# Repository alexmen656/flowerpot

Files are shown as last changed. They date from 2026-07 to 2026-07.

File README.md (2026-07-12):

# Smart Flower Pot

With this smart flower pot you will never forget to water your plants. If you don't water it within a time interval you can set on the screen, 3 speakers will scream at you until the motion sensor detects movement (you watering the plant) - it won't stop. It also monitors the humidity, temperature and light conditions of your plant and displays it on the screen.

## BOM

| Qty | Part | Source |
|-----|---|---|
| 3 | Speakers | [AliExpress](https://de.aliexpress.com/item/1005010806449882.html) |
| 3 | Amplifiers | [AliExpress](https://de.aliexpress.com/item/1005012452360614.html) |
| 1 | Orpheus Pico | Got it from HackClub |
| 1 | XIAO RP2040 | [AliExpress](https://de.aliexpress.com/item/1005012441490478.html) |
| - | Jumper wires | Like a lot of them! |
| 1 | 2.8" TFT display | [AliExpress](https://de.aliexpress.com/item/1005010008924503.html) |
| - | 3D printer filament (for the pot) | Any filament |
| 1 | DHT11 sensor | [AliExpress](https://de.aliexpress.com/item/1005008953430940.html) |
| 1 | Motion sensor (HC-SR501) | [AliExpress](https://de.aliexpress.com/item/4001234886268.html) |

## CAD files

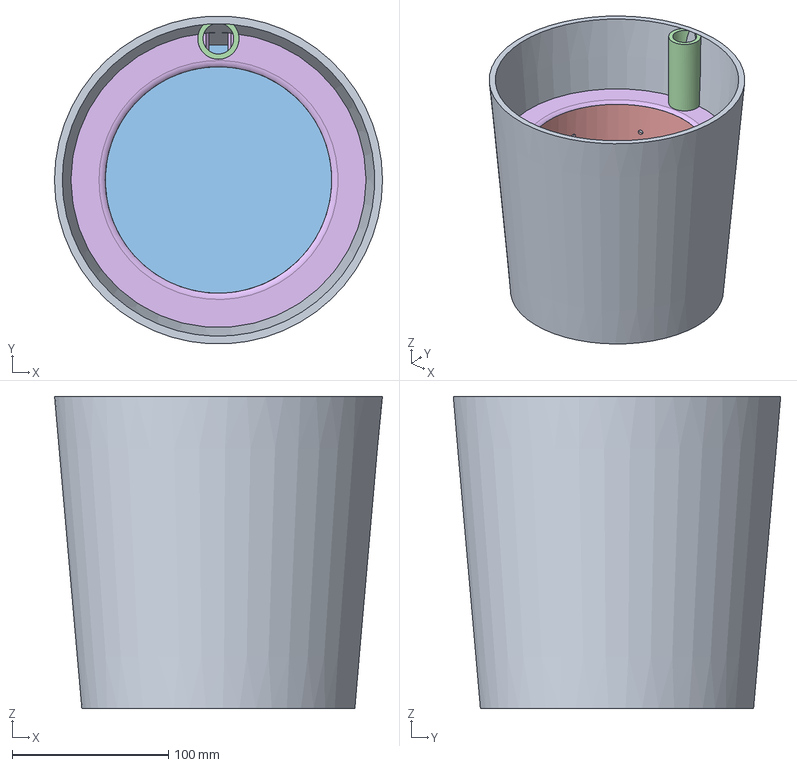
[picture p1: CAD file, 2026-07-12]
CAD/plant_pot.stp
210.0 x 209.6 x 200.0 mm

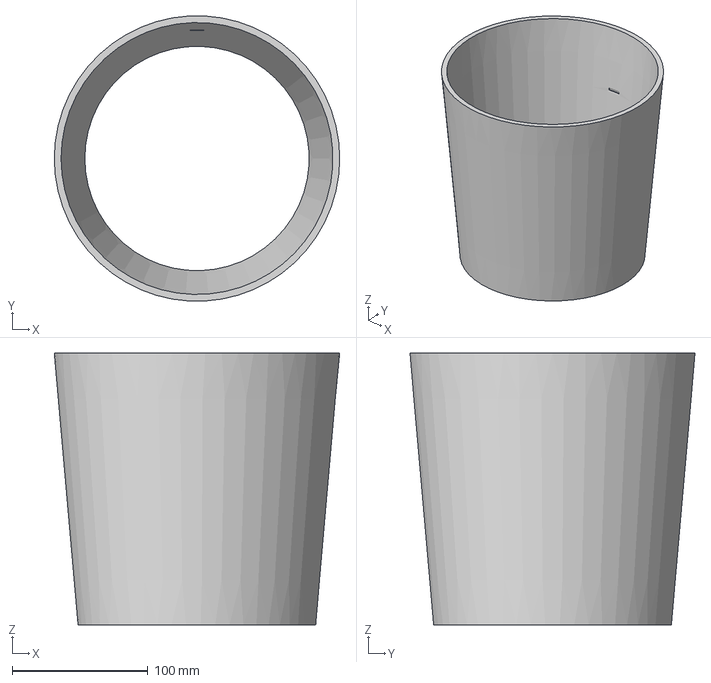
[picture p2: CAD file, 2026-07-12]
CAD/plant_pot_top.step
210.0 x 209.6 x 200.0 mm

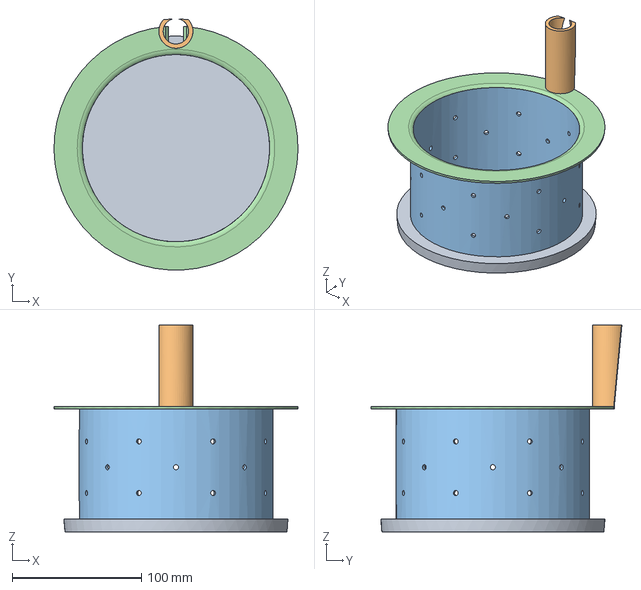
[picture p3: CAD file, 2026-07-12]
CAD/plant_pot_middle.step
189.0 x 194.3 x 160.0 mm

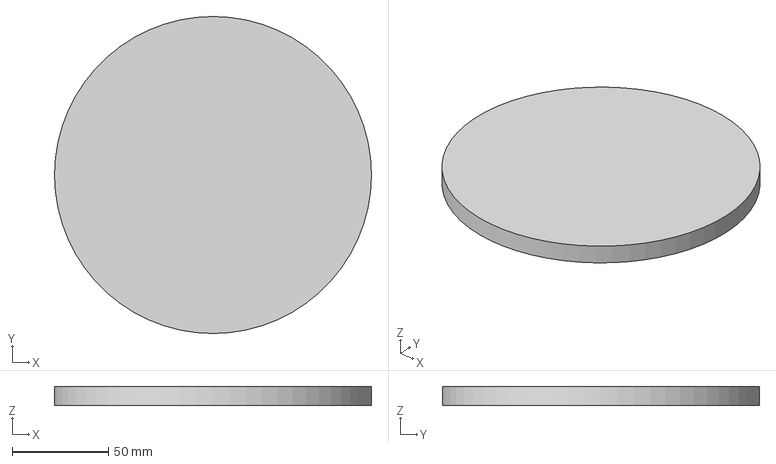
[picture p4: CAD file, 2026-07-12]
CAD/plant_pot_bottom.step
165.0 x 165.0 x 10.0 mm

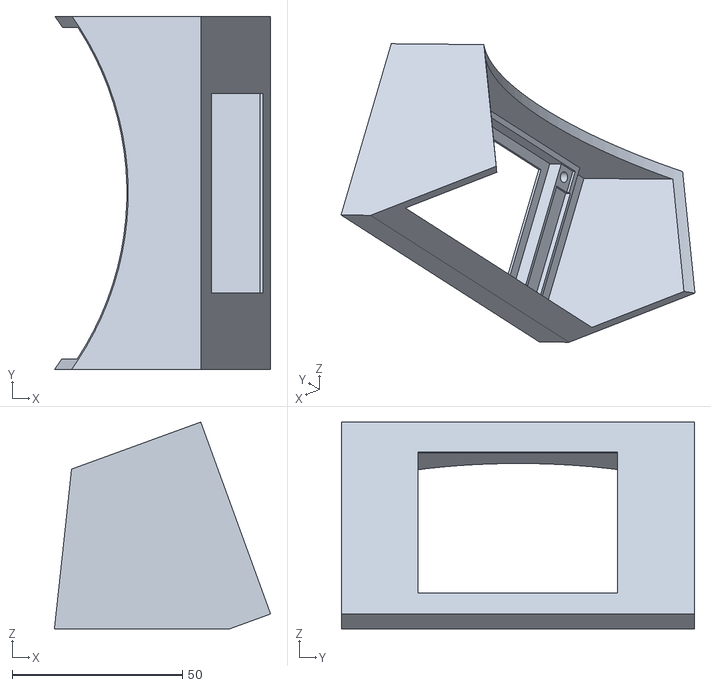
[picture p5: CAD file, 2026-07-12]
CAD/display.stl
63.6 x 103.7 x 60.8

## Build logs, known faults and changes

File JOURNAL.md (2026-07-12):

# 1. CAD - around 2 hours
The CAD was pretty simple and straightforward

# 2. Putting everything together - 8 hours
This was the hardest part because of the many components I had to solder together. The speakers were very frustrating because they needed amplifiers, so I had to solder around 15 wires for each speaker. The rest wasn't that hard, just time consuming

# 3. Adding a Display - 3 hours
Initially I didn't plan to have a display, but then I decided later that it would be much cooler to have one - so I designed the display cover and added a 2.8 inch TFT screen

# 4. Idea for adding a LED strip
I also wanted to add a LED strip to the top, but the Pico didn't have enough power, so I didn't finish that.

# 5. Firmware - 2 hours
Firmware was a bit more complicated than I thought. TBH, AI assisted me with this step for like 50%, because the display added much more complexity with displaying a nice layout and icons. I used MicroPython for the firmware

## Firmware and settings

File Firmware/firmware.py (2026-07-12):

import machine
import random
import time
from micropython import const
import ustruct as struct
import math
import dht  # DHT11/DHT22 sensor support
from machine import I2S, Pin
import array

# ILI9341 command set
ILI9341_SWRESET = const(0x01)
ILI9341_SLPOUT = const(0x11)
ILI9341_DISPON = const(0x29)
ILI9341_CASET = const(0x2A)
ILI9341_PASET = const(0x2B)
ILI9341_RAMWR = const(0x2C)
ILI9341_MADCTL = const(0x36)
ILI9341_PIXFMT = const(0x3A)
ILI9341_PWCTR1 = const(0xC0)
ILI9341_PWCTR2 = const(0xC1)
ILI9341_VMCTR1 = const(0xC5)
ILI9341_VMCTR2 = const(0xC7)
ILI9341_FRMCTR1 = const(0xB1)
ILI9341_DFUNCTR = const(0xB6)
ILI9341_GAMMASET = const(0x26)
ILI9341_GMCTRP1 = const(0xE0)
ILI9341_GMCTRN1 = const(0xE1)

MADCTL_MX = const(0x40)
MADCTL_BGR = const(0x08)

# Color palette (RGB565)
GREEN_LIGHT = const(0x87E0)
GREEN_DARK = const(0x0400)
BLUE_LIGHT = const(0x3D7F)
BLUE_DARK = const(0x001F)
ORANGE = const(0xFD20)
RED = const(0xF800)
YELLOW = const(0xFFE0)
WHITE = const(0xFFFF)
BLACK = const(0x0000)
GRAY_LIGHT = const(0xCE79)
GRAY_DARK = const(0x7BEF)
BROWN = const(0x8200)

# Touch controller commands (XPT2046/ADS7843)
TOUCH_CMD_X = const(0x90)
TOUCH_CMD_Y = const(0xD0)

def delay_ms(ms):
    time.sleep_ms(ms)

def color565(r, g=0, b=0):
    """Convert RGB to 565 format"""
    try:
        r, g, b = r
    except TypeError:
        pass
    return (r & 0xf8) << 8 | (g & 0xfc) << 3 | b >> 3

class TouchController:
    def __init__(self, spi, cs, irq):
        self.spi = spi
        self.cs = cs
        self.irq = irq
        self.cs.on()  # CS high (inactive)

        # Calibration values, may need adjusting per panel
        self.cal_x_min = 200
        self.cal_x_max = 3800
        self.cal_y_min = 200
        self.cal_y_max = 3800

        self.test_connection()

    def test_connection(self):
        """Tests the connection to the touch controller"""
        print("Testing touch controller connection...")

        irq_state = self.irq.value()
        print(f"IRQ pin state: {irq_state} (1=no touch, 0=touch detected)")

        try:
            test_x = self.read_touch_raw(TOUCH_CMD_X)
            test_y = self.read_touch_raw(TOUCH_CMD_Y)
            print(f"Touch test values: X={test_x}, Y={test_y}")

            if test_x == 0 and test_y == 0:
                print("Warning: touch controller not responding correctly")
            else:
                print("Touch controller responding")

        except Exception as e:
            print(f"Touch controller error: {e}")

    def read_touch_raw(self, cmd):
        """Reads a raw touch sample"""
        self.cs.off()
        delay_ms(1)

        self.spi.write(bytes([cmd]))

        delay_ms(1)
        result = self.spi.read(2)

        delay_ms(1)
        self.cs.on()

        if len(result) == 2:
            # 12-bit resolution (ADS7843/XPT2046)
            value = (result[0] << 8 | result[1]) >> 3
            return value & 0x0FFF
        return 0

    def get_touch(self):
        """Returns the touch position, or None if there's no touch"""
        irq_state = self.irq.value()

        if irq_state == 1:  # IRQ is HIGH when not pressed
            return None

        # Average a few samples for stability
        x_sum = y_sum = 0
        valid_readings = 0

        for i in range(3):
            x_raw = self.read_touch_raw(TOUCH_CMD_X)
            y_raw = self.read_touch_raw(TOUCH_CMD_Y)

            if i == 0:
                print(f"Touch raw: X={x_raw}, Y={y_raw}, IRQ={irq_state}")

            if x_raw > 100 and y_raw > 100 and x_raw < 4000 and y_raw < 4000:
                x_sum += x_raw
                y_sum += y_raw
                valid_readings += 1

        if valid_readings == 0:
            print("No valid touch readings")
            return None

        x_avg = x_sum // valid_readings
        y_avg = y_sum // valid_readings

        # Map to screen coordinates
        x = int((x_avg - self.cal_x_min) * 320 / (self.cal_x_max - self.cal_x_min))
        y = int((y_avg - self.cal_y_min) * 240 / (self.cal_y_max - self.cal_y_min))

        x = max(0, min(319, x))
        y = max(0, min(239, y))

        print(f"Touch calculated: X={x}, Y={y} (raw avg: {x_avg}, {y_avg})")
        return (x, y)

class SmartPlantDisplay:
    def __init__(self, spi, dc, reset, cs=None, touch=None):
        self.spi = spi
        self.dc = dc
        self.reset = reset
        self.cs = cs
        self.touch = touch
        self.width = 320
        self.height = 240
        self.current_screen = 0
        self.last_update = 0
        self.last_touch_time = 0
        self.manual_mode = False  # touch disables auto screen switching
        self.last_drawn_screen = -1
        self.screen_needs_redraw = True
        self.last_light_value = 0
        self.data_needs_update = False  # value-only update without full redraw

        # Motion sensor tracking
        self.last_motion_time = 0
        self.motion_timeout = 30000  # ms, adjustable
        self.motion_timeout_seconds = 30  # for UI display, adjustable
        self.last_motion_check = 0
        self.audio_played = False
        self.reward_played = False

        # I2S audio system for punishment/reward sounds
        self.i2s = None
        self.setup_audio_system()

        # Last displayed values, for change detection
        self.last_displayed_values = {
            'light': 0,
            'temperature': 0,
            'humidity': 0,
            'plant_health': 0
        }

        # Sensors
        self.light_sensor = machine.ADC(machine.Pin(28))  # GP28 = ADC2, light sensor
        self.dht_sensor = dht.DHT11(machine.Pin(27))      # GP27, temp/humidity sensor
        self.motion_pin = machine.Pin(26, machine.Pin.IN) # GP26, motion sensor

        current_time = time.ticks_ms()
        self.last_motion_time = current_time  # start as if motion was just detected
        print(f"Motion sensor initialized - {self.motion_timeout_seconds}s timer started")

        # Simulated sensor data, used as fallback when a real sensor is unavailable
        self.sensor_data = {
            'temperature': 22.5,
            'humidity': 65,
            'light': 750,
            'light_voltage': 1.65,
            'light_raw': 32767,
            'water_level': 80,
            'plant_health': 85
        }

    # Low-level display functions
    def dc_low(self):
        self.dc.off()

    def dc_high(self):
        self.dc.on()

    def cs_low(self):
        if self.cs:
            self.cs.off()

    def cs_high(self):
        if self.cs:
            self.cs.on()

    def write_cmd(self, cmd):
        self.cs_low()
        self.dc_low()
        self.spi.write(bytes([cmd]))
        self.cs_high()

    def write_data(self, data):
        self.cs_low()
        self.dc_high()
        if isinstance(data, int):
            self.spi.write(bytes([data]))
        else:
            self.spi.write(data)
        self.cs_high()

    def write_cmd_data(self, cmd, data=None):
        self.cs_low()
        self.dc_low()
        self.spi.write(bytes([cmd]))
        if data is not None:
            self.dc_high()
            if isinstance(data, int):
                self.spi.write(bytes([data]))
            else:
                self.spi.write(data)
        self.cs_high()

    def init(self):
        """Initializes the display controller"""
        print("Initializing display...")

        if self.reset:
            self.reset.off()
            delay_ms(100)
            self.reset.on()
            delay_ms(100)

        self.write_cmd(ILI9341_SWRESET)
        delay_ms(150)

        self.write_cmd(ILI9341_SLPOUT)
        delay_ms(120)

        self.write_cmd_data(0xCB, bytes([0x39, 0x2C, 0x00, 0x34, 0x02]))
        self.write_cmd_data(0xCF, bytes([0x00, 0xC1, 0x30]))
        self.write_cmd_data(ILI9341_PWCTR1, 0x23)
        self.write_cmd_data(ILI9341_PWCTR2, 0x10)
        self.write_cmd_data(ILI9341_VMCTR1, bytes([0x3e, 0x28]))
        self.write_cmd_data(ILI9341_VMCTR2, 0x86)
        self.write_cmd_data(ILI9341_MADCTL, 0x88)  # MY(0x80) | BGR(0x08), 270° rotation
        self.write_cmd_data(ILI9341_PIXFMT, 0x55)
        self.write_cmd_data(ILI9341_FRMCTR1, bytes([0x00, 0x18]))

        self.write_cmd(ILI9341_DISPON)
        delay_ms(100)

        print("Display ready")

    def set_window(self, x0, y0, x1, y1):
        self.write_cmd_data(ILI9341_CASET, struct.pack(">HH", x0, x1))
        self.write_cmd_data(ILI9341_PASET, struct.pack(">HH", y0, y1))
        self.write_cmd(ILI9341_RAMWR)

    def fill_rect(self, x, y, w, h, color):
        if x + w > self.width:
            w = self.width - x
        if y + h > self.height:
            h = self.height - y

        self.set_window(x, y, x + w - 1, y + h - 1)
        pixel_data = struct.pack(">H", color)

        self.cs_low()
        self.dc_high()
        for _ in range(w * h):
            self.spi.write(pixel_data)
        self.cs_high()

    def fill(self, color):
        self.fill_rect(0, 0, self.width, self.height, color)

    def pixel(self, x, y, color):
        if 0 <= x < self.width and 0 <= y < self.height:
            self.set_window(x, y, x, y)
            self.write_data(struct.pack(">H", color))

    def hline(self, x, y, w, color):
        self.fill_rect(x, y, w, 1, color)

    def vline(self, x, y, h, color):
        self.fill_rect(x, y, 1, h, color)

    # UI drawing helpers
    def draw_rounded_rect(self, x, y, w, h, radius, color):
        """Draws a rounded rectangle"""
        self.fill_rect(x + radius, y, w - 2*radius, h, color)
        self.fill_rect(x, y + radius, radius, h - 2*radius, color)
        self.fill_rect(x + w - radius, y + radius, radius, h - 2*radius, color)

        # Corners
        for i in range(radius):
            for j in range(radius):
                if i*i + j*j <= radius*radius:
                    self.pixel(x + radius - i, y + radius - j, color)
                    self.pixel(x + w - radius + i, y + radius - j, color)
                    self.pixel(x + radius - i, y + h - radius + j, color)
                    self.pixel(x + w - radius + i, y + h - radius + j, color)

    def draw_circle(self, cx, cy, radius, color):
        """Draws a filled circle"""
        for x in range(-radius, radius + 1):
            for y in range(-radius, radius + 1):
                if x*x + y*y <= radius*radius:
                    self.pixel(cx + x, cy + y, color)

    def draw_progress_bar(self, x, y, w, h, value, max_value, bg_color, fg_color):
        """Draws a progress bar"""
        self.draw_rounded_rect(x, y, w, h, 3, bg_color)

        progress_w = int((value / max_value) * (w - 4))
        if progress_w > 0:
            self.draw_rounded_rect(x + 2, y + 2, progress_w, h - 4, 2, fg_color)

    def draw_digit(self, x, y, digit, size, color):
        """Draws a single digit as a 7-segment display"""
        segments = [
            [1,1,1,1,1,1,0], # 0
            [0,1,1,0,0,0,0], # 1
            [1,1,0,1,1,0,1], # 2
            [1,1,1,1,0,0,1], # 3
            [0,1,1,0,0,1,1], # 4
            [1,0,1,1,0,1,1], # 5
            [1,0,1,1,1,1,1], # 6
            [1,1,1,0,0,0,0], # 7
            [1,1,1,1,1,1,1], # 8
            [1,1,1,1,0,1,1]  # 9
        ]

        if 0 <= digit <= 9:
            seg = segments[digit]
            w = size * 6
            h = size * 10

            if seg[0]: self.fill_rect(x+size, y, w-2*size, size, color)           # top
            if seg[1]: self.fill_rect(x+w-size, y+size, size, h//2-size, color)  # top right
            if seg[2]: self.fill_rect(x+w-size, y+h//2, size, h//2-size, color)  # bottom right
            if seg[3]: self.fill_rect(x+size, y+h-size, w-2*size, size, color)   # bottom
            if seg[4]: self.fill_rect(x, y+h//2, size, h//2-size, color)         # bottom left
            if seg[5]: self.fill_rect(x, y+size, size, h//2-size, color)         # top left
            if seg[6]: self.fill_rect(x+size, y+h//2-size//2, w-2*size, size, color) # middle

    def draw_number(self, x, y, number, size, color):
        """Draws a multi-digit number"""
        num_str = str(int(number))
        digit_width = size * 8

        for i, digit_char in enumerate(num_str):
            digit = int(digit_char)
            digit_x = x + i * digit_width
            self.draw_digit(digit_x, y, digit, size, color)

    def draw_icon_plant(self, x, y, size, color):
        """Draws a plant icon"""
        stem_x = x + size // 2
        self.vline(stem_x, y + size//3, size//2, GREEN_DARK)

        self.draw_circle(x + size//4, y + size//4, size//6, color)
        self.draw_circle(x + 3*size//4, y + size//4, size//6, color)
        self.draw_circle(x + size//2, y + size//6, size//5, color)

    def draw_icon_water(self, x, y, size, color):
        """Draws a water drop icon"""
        self.draw_circle(x + size//2, y + size//2, size//3, color)

    def draw_icon_temperature(self, x, y, size, color):
        """Draws a thermometer icon"""
        therm_x = x + size//2
        self.vline(therm_x, y + size//4, size//2, color)
        self.draw_circle(therm_x, y + 3*size//4, size//8, color)

    def draw_icon_sun(self, x, y, size, color):
        """Draws a sun icon"""
        center_x, center_y = x + size//2, y + size//2
        radius = size//4

        for angle in range(0, 360, 45):
            angle_rad = angle * 3.14159 / 180
            x1 = center_x + int(radius * 1.5 * math.cos(angle_rad))
            y1 = center_y + int(radius * 1.5 * math.sin(angle_rad))
            x2 = center_x + int(radius * 2 * math.cos(angle_rad))
            y2 = center_y + int(radius * 2 * math.sin(angle_rad))

            for i in range(3):
                if 0 <= x1+i < self.width and 0 <= y1 < self.height:
                    self.pixel(x1+i, y1, color)

        self.draw_circle(center_x, center_y, radius, color)

    def read_light_sensor(self):
        """Reads the light sensor (ADC)"""
        try:
            raw = self.light_sensor.read_u16()  # 0 to 65535
            voltage = raw * 3.3 / 65535

            # Map to a lux-like range (0-1000); may need calibration
            light_value = int((raw / 65535) * 1000)

            return light_value, voltage, raw
        except Exception as e:
            print(f"Light sensor error: {e}")
            return 500, 1.65, 32767  # fallback values

    def read_temp_humidity_sensor(self):
        """Reads the DHT11 temperature/humidity sensor"""
        try:
            self.dht_sensor.measure()
            temperature = self.dht_sensor.temperature()
            humidity = self.dht_sensor.humidity()

            print(f"DHT11 - Temp: {temperature}C, Humidity: {humidity}%")
            return temperature, humidity

        except OSError as e:
            print(f"DHT11 sensor error: {e} (not connected or faulty?)")
            return None, None
        except Exception as e:
            print(f"DHT11 unknown error: {e}")
            return None, None

    def read_motion_sensor(self):
        """Reads the motion sensor and triggers reward/punishment audio based on the timeout"""
        try:
            current_time = time.ticks_ms()
            motion_state = self.motion_pin.value()

            if motion_state == 1:  # motion detected -> reward
                self.last_motion_time = current_time
                self.audio_played = False

                # Only play the reward sound once per motion event
                if not self.reward_played:
                    print("Motion detected - watering detected")
                    self.play_reward_sound()
                    self.reward_played = True

                return True
            else:
                self.reward_played = False

            # Check the timeout every 5s to avoid spamming
            if time.ticks_diff(current_time, self.last_motion_check) > 5000:
                self.last_motion_check = current_time

                if time.ticks_diff(current_time, self.last_motion_time) > self.motion_timeout:
                    print(f"No motion for {self.motion_timeout_seconds}+ seconds - punishment")

                    # Only play the punishment sound once per timeout period
                    if not self.audio_played:
                        self.play_punishment_sound()
                        self.audio_played = True

            return False

        except Exception as e:
            print(f"Motion sensor error: {e}")
            return False

    def setup_audio_system(self):
        """Initializes the I2S audio system"""
        try:
            self.i2s = I2S(
                0,
                sck=Pin(10),    # BCLK
                ws=Pin(11),     # LRC / WS
                sd=Pin(12),     # DIN
                mode=I2S.TX,
                bits=16,
                format=I2S.MONO,
                rate=22050,
                ibuf=20000,
            )
            print("I2S audio system initialized (GP10=BCLK, GP11=WS, GP12=DIN)")
        except Exception as e:
            print(f"I2S audio system error: {e}")
            self.i2s = None

    def play_punishment_sound(self):
        """Plays the punishment sound: a 5s, 3000 Hz sine wave"""
        if not self.i2s:
            print("I2S not available - no sound")
            return

        try:
            print("Punishment: playing sine wave (5s, 3000 Hz)")

            sample_rate = 22050
            frequency = 3000
            amplitude = 32767  # max for 16-bit audio
            duration = 5
            samples_per_cycle = sample_rate // frequency

            sine_wave = array.array("h", [
                int(amplitude * math.sin(2 * math.pi * i / samples_per_cycle))
                for i in range(samples_per_cycle)
            ])

            num_cycles = int(sample_rate * duration // samples_per_cycle)
            for cycle in range(num_cycles):
                self.i2s.write(sine_wave)
                if cycle % 50 == 0:
                    time.sleep_ms(1)

            print("Punishment sound finished")

        except Exception as e:
            print(f"Audio playback error: {e}")

    def play_reward_sound(self):
        """Plays the reward sound: a short major-chord melody"""
        if not self.i2s:
            print("I2S not available - no reward sound")
            return

        try:
            print("Reward: playing melody (good plant care!)")

            sample_rate = 22050
            amplitude = 16383  # quieter than the punishment sound
            duration = 2

            # C major triad progression
            frequencies = [
                261.63,  # C4
                329.63,  # E4
                392.00,  # G4
                523.25   # C5
            ]

            note_duration = 0.5

            for freq in frequencies:
                samples_per_cycle = sample_rate // int(freq)

                sine_wave = array.array("h", [
                    int(amplitude * math.sin(2 * math.pi * i / samples_per_cycle))
                    for i in range(samples_per_cycle)
                ])

                num_cycles = int(sample_rate * note_duration // samples_per_cycle)
                for cycle in range(num_cycles):
                    self.i2s.write(sine_wave)
                    if cycle % 20 == 0:
                        time.sleep_ms(1)

            print("Reward melody finished")

        except Exception as e:
            print(f"Reward audio error: {e}")

    def cleanup_audio(self):
        """Tears down the audio system"""
        if self.i2s:
            try:
                self.i2s.deinit()
                print("I2S audio system stopped")
            except:
                pass
            self.i2s = None

    def show_main_screen(self):
        """Draws the main dashboard screen"""
        self.fill(BLACK)

        y_start = 20

        # Row 1: temperature (1 box) + light (2 boxes)
        color = GRAY_LIGHT

        # Temperature widget
        self.draw_rounded_rect(10, y_start, 90, 80, 8, color)
        self.draw_icon_temperature(20, y_start + 10, 30, ORANGE)
        self.draw_number(20, y_start + 45, self.sensor_data['temperature'], 2, ORANGE)

        # Light widget, spans 2 boxes
        light_value = int(self.sensor_data['light'])
        light_color = self.get_light_quality_color(light_value)
        light_description = self.get_light_quality_description(light_value)

        self.draw_rounded_rect(110, y_start, 200, 80, 8, color)
        self.draw_icon_sun(120, y_start + 10, 60, light_color)

        # Light quality label, next to the icon
        text_x = 190
        text_y = y_start + 20

        if len(light_description) > 10:
            words = light_description.split()
            if len(words) >= 2:
                self.draw_simple_text_2x(text_x, text_y, words[0], light_color)
                self.draw_simple_text_2x(text_x, text_y + 20, words[1], light_color)
            else:
                short_desc = light_description[:10]
                self.draw_simple_text_2x(text_x, text_y, short_desc, light_color)
        else:
            self.draw_simple_text_2x(text_x, text_y, light_description, light_color)

        # Row 2: humidity (1 box) + plant health (2 boxes)
        self.draw_rounded_rect(10, y_start + 90, 90, 80, 8, color)
        self.draw_icon_water(20, y_start + 100, 30, BLUE_LIGHT)
        self.draw_number(20, y_start + 135, self.sensor_data['humidity'], 2, BLUE_LIGHT)

        self.draw_rounded_rect(110, y_start + 90, 200, 80, 8, color)
        health = self.sensor_data['plant_health']

        if health > 80:
            status_color = GREEN_LIGHT
        elif health > 60:
            status_color = YELLOW
        else:
            status_color = RED

        self.draw_progress_bar(120, y_start + 110, 180, 25, health, 100, GRAY_DARK, status_color)
        self.draw_simple_text(115, y_start + 95, "HEALTH", status_color)
        self.draw_number(270, y_start + 95, health, 1, status_color)

        self.draw_bottom_navigation_bar()
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

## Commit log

2026-07-12 Add CAD
    [display.stl, plant_pot.stp, plant_pot_bottom.step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]
2026-07-12 Add BOM
